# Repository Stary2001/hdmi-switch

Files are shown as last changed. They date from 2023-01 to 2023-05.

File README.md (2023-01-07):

## USB controlled HDMI Switch

I couldn't find one of these easily, so I decided to make one myself.

This uses a PI3HDX621 `3.4Gbps HDMI1.4b Active 2:1 Switch with ARC and Fast Switching` paired with a SAMD21 microcontroller (because I had some in stock).

The firmware is implemented with my library [libsam](https://github.com/Stary2001/libsam).

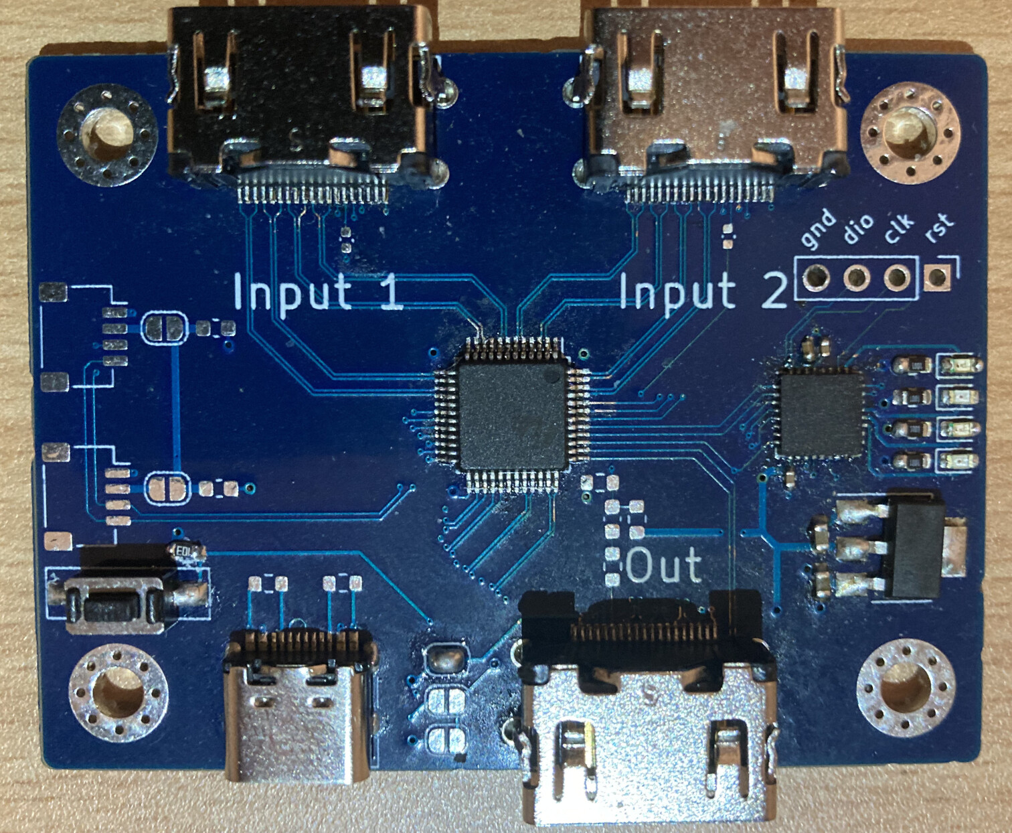
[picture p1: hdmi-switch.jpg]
Picture of the board - with two HDMI ports labelled Input 1 and 2, and a third labelled Out.


Untested things - the switch IC supports ARC, but I didn't test that yet because I don't have anything handy that supports it.

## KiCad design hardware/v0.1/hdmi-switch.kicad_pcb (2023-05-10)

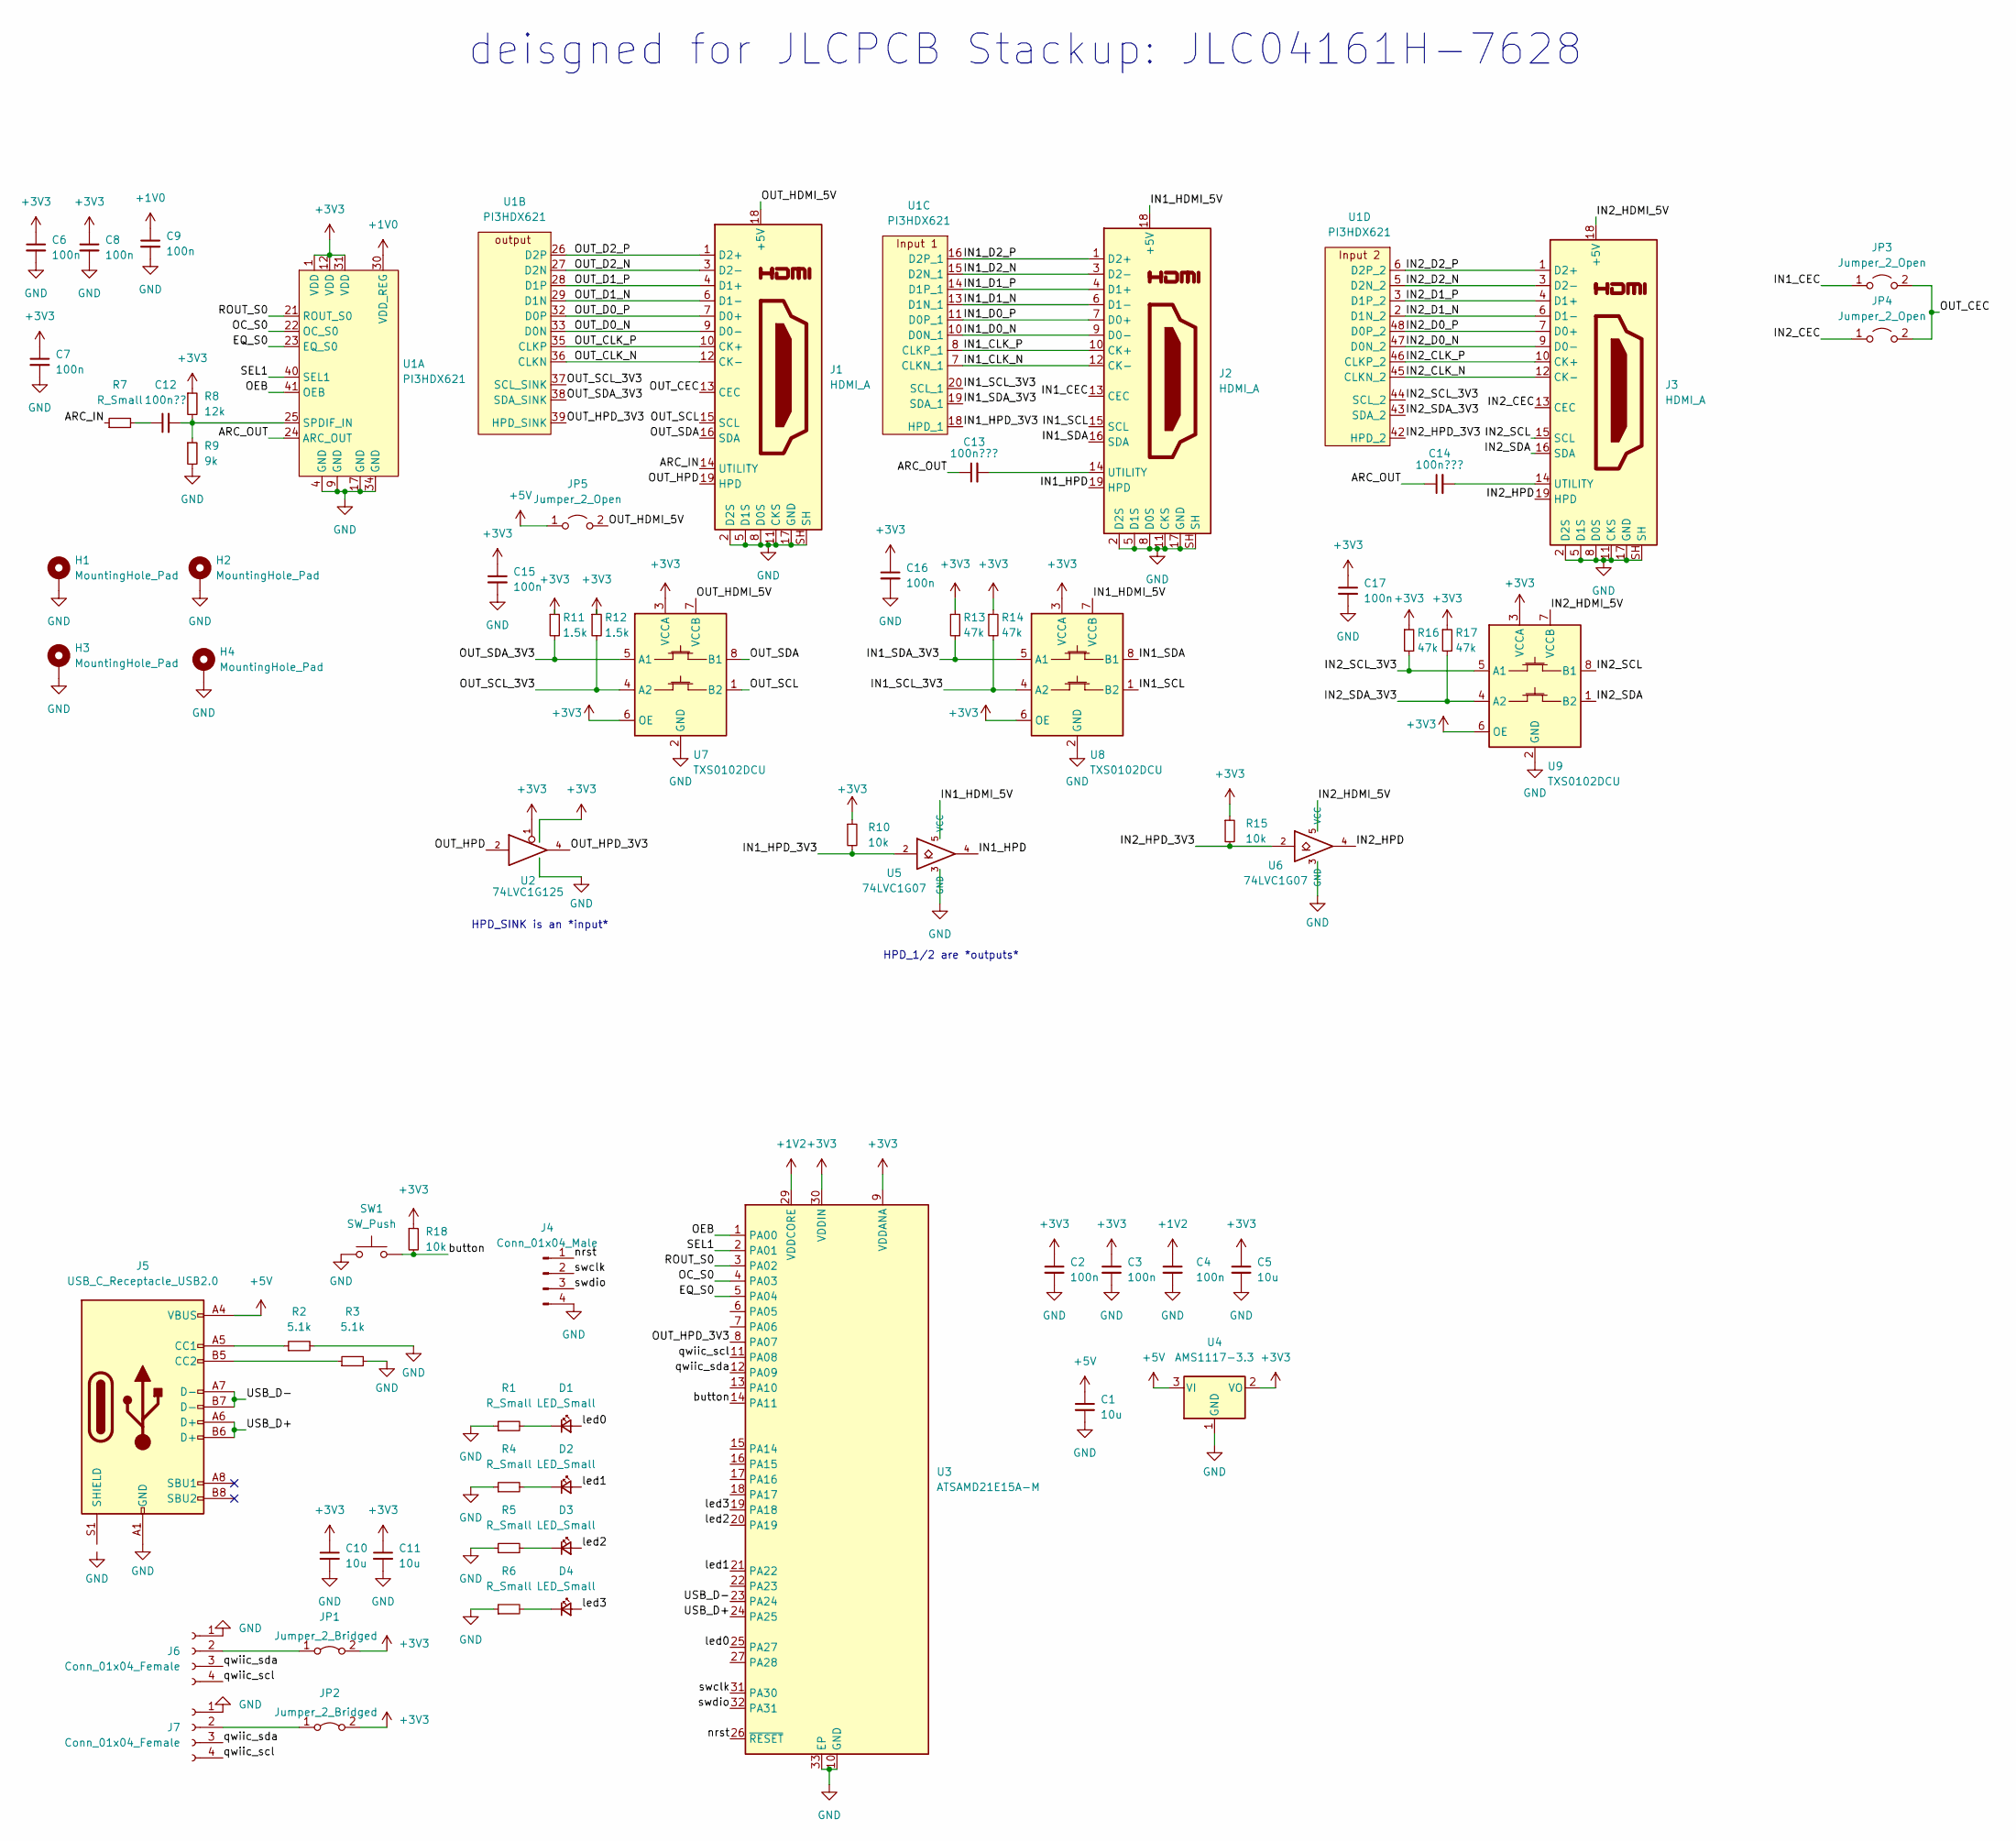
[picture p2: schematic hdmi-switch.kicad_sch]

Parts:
C1, C5, C10, C11: 10u; C_0603_1608Metric
C2, C3, C4, C6, C7, C8, C15, C16, C17: 100n; C_0402_1005Metric
C9: 100n; C_0603_1608Metric
C12: 100n??; C_0603_1608Metric
C13, C14: 100n???; C_0402_1005Metric
D1, D2, D3, D4: LED_Small; LED_0603_1608Metric
H1, H2, H3, H4: MountingHole_Pad; MountingHole_3.2mm_M3_Pad_Via
J1, J2, J3: HDMI_A; HDMI-SS-53000
J4: Conn_01x04_Male; PinHeader_1x04_P2.54mm_Vertical
J5: USB_C_Receptacle_USB2.0; USB_C_Receptacle_HRO_TYPE-C-31-M-12
J6, J7: Conn_01x04_Female; JST_SH_SM04B-SRSS-TB_1x04-1MP_P1.00mm_Horizontal
JP1, JP2: Jumper_2_Bridged; SolderJumper-2_P1.3mm_Open_RoundedPad1.0x1.5mm
JP3, JP4, JP5: Jumper_2_Open; SolderJumper-2_P1.3mm_Open_RoundedPad1.0x1.5mm
R1, R4, R5, R6, R7: R_Small; R_0603_1608Metric
R2, R3: 5.1k; R_0603_1608Metric
R8: 12k; R_0603_1608Metric
R9: 9k; R_0603_1608Metric
R10, R15, R18: 10k; R_0603_1608Metric
R11, R12: 1.5k; R_0603_1608Metric
R13, R14, R16, R17: 47k; R_0603_1608Metric
SW1: SW_Push; PTS636
U1: PI3HDX621; LQFP-48_7x7mm_P0.5mm
U2: 74LVC1G125; SOT-23-5
U3: ATSAMD21E15A-M; QFN-32-1EP_5x5mm_P0.5mm_EP3.6x3.6mm
U4: AMS1117-3.3; SOT-223-3_TabPin2
U5, U6: 74LVC1G07; SOT-23-5
U7, U8, U9: TXS0102DCU; VSSOP-8_2.3x2mm_P0.5mm

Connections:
+1V0: C9.1, U1.30 (VDD_REG)
+1V2: C4.1, U3.29 (VDDCORE)
+3V3: C2.1, C3.1, C5.1, C6.1, C7.1, C8.1, C10.1, C11.1, C15.1, C16.1, C17.1, JP1.2 (B), JP2.2 (B), R8.1, R10.1, R11.1, R12.1, R13.1, R14.1, R15.1, R16.1, R17.1, R18.1, U1.1 (VDD), U1.12 (VDD), U1.31 (VDD), U2.1, U2.5 (VCC), U3.9 (VDDANA), U3.30 (VDDIN), U4.2 (VO), U7.3 (VCCA), U7.6 (OE), U8.3 (VCCA), U8.6 (OE), U9.3 (VCCA), U9.6 (OE)
+5V: C1.1, J5.A4 (VBUS), J5.A9 (VBUS), J5.B4 (VBUS), J5.B9 (VBUS), JP5.1 (A), U4.3 (VI)
/ARC_IN: J1.14 (UTILITY), R7.1
/ARC_OUT: C13.1, C14.1, U1.24 (ARC_OUT)
/EQ_S0: U1.23 (EQ_S0), U3.5 (PA04)
/IN1_CEC: J2.13 (CEC), JP3.1 (A)
/IN1_CLK_N: J2.12 (CK-), U1.7 (CLKN_1)
/IN1_CLK_P: J2.10 (CK+), U1.8 (CLKP_1)
/IN1_D0_N: J2.9 (D0-), U1.10 (D0N_1)
/IN1_D0_P: J2.7 (D0+), U1.11 (D0P_1)
/IN1_D1_N: J2.6 (D1-), U1.13 (D1N_1)
/IN1_D1_P: J2.4 (D1+), U1.14 (D1P_1)
/IN1_D2_N: J2.3 (D2-), U1.15 (D2N_1)
/IN1_D2_P: J2.1 (D2+), U1.16 (D2P_1)
/IN1_HDMI_5V: J2.18 (+5V), U5.5 (VCC), U8.7 (VCCB)
/IN1_HPD: J2.19 (HPD), U5.4
/IN1_HPD_3V3: R10.2, U1.18 (HPD_1), U5.2
/IN1_SCL: J2.15 (SCL), U8.1 (B2)
/IN1_SCL_3V3: R14.2, U1.20 (SCL_1), U8.4 (A2)
/IN1_SDA: J2.16 (SDA), U8.8 (B1)
/IN1_SDA_3V3: R13.2, U1.19 (SDA_1), U8.5 (A1)
/IN2_CEC: J3.13 (CEC), JP4.1 (A)
/IN2_CLK_N: J3.12 (CK-), U1.45 (CLKN_2)
/IN2_CLK_P: J3.10 (CK+), U1.46 (CLKP_2)
/IN2_D0_N: J3.9 (D0-), U1.47 (D0N_2)
/IN2_D0_P: J3.7 (D0+), U1.48 (D0P_2)
/IN2_D1_N: J3.6 (D1-), U1.2 (D1N_2)
/IN2_D1_P: J3.4 (D1+), U1.3 (D1P_2)
/IN2_D2_N: J3.3 (D2-), U1.5 (D2N_2)
/IN2_D2_P: J3.1 (D2+), U1.6 (D2P_2)
/IN2_HDMI_5V: J3.18 (+5V), U6.5 (VCC), U9.7 (VCCB)
/IN2_HPD: J3.19 (HPD), U6.4
/IN2_HPD_3V3: R15.2, U1.42 (HPD_2), U6.2
/IN2_SCL: J3.15 (SCL), U9.8 (B1)
/IN2_SCL_3V3: R16.2, U1.44 (SCL_2), U9.5 (A1)
/IN2_SDA: J3.16 (SDA), U9.1 (B2)
/IN2_SDA_3V3: R17.2, U1.43 (SDA_2), U9.4 (A2)
/OC_S0: U1.22 (OC_S0), U3.4 (PA03)
/OEB: U1.41 (OEB), U3.1 (PA00)
/OUT_CEC: J1.13 (CEC), JP3.2 (B), JP4.2 (B)
/OUT_CLK_N: J1.12 (CK-), U1.36 (CLKN)
/OUT_CLK_P: J1.10 (CK+), U1.35 (CLKP)
/OUT_D0_N: J1.9 (D0-), U1.33 (D0N)
/OUT_D0_P: J1.7 (D0+), U1.32 (D0P)
/OUT_D1_N: J1.6 (D1-), U1.29 (D1N)
/OUT_D1_P: J1.4 (D1+), U1.28 (D1P)
/OUT_D2_N: J1.3 (D2-), U1.27 (D2N)
/OUT_D2_P: J1.1 (D2+), U1.26 (D2P)
/OUT_HDMI_5V: J1.18 (+5V), JP5.2 (B), U7.7 (VCCB)
/OUT_HPD: J1.19 (HPD), U2.2
/OUT_HPD_3V3: U1.39 (HPD_SINK), U2.4, U3.8 (PA07)
/OUT_SCL: J1.15 (SCL), U7.1 (B2)
/OUT_SCL_3V3: R12.2, U1.37 (SCL_SINK), U7.4 (A2)
/OUT_SDA: J1.16 (SDA), U7.8 (B1)
/OUT_SDA_3V3: R11.2, U1.38 (SDA_SINK), U7.5 (A1)
/ROUT_S0: U1.21 (ROUT_S0), U3.3 (PA02)
/SEL1: U1.40 (SEL1), U3.2 (PA01)
/USB_D+: J5.A6 (D+), J5.B6 (D+), U3.24 (PA25)
/USB_D-: J5.A7 (D-), J5.B7 (D-), U3.23 (PA24)
/button: R18.2, SW1.2, U3.14 (PA11)
/led0: D1.2 (A), U3.25 (PA27)
/led1: D2.2 (A), U3.21 (PA22)
/led2: D3.2 (A), U3.20 (PA19)
/led3: D4.2 (A), U3.19 (PA18)
/nrst: J4.1, U3.26 (~RESET)
/qwiic_scl: J6.4, J7.4, U3.11 (PA08)
/qwiic_sda: J6.3, J7.3, U3.12 (PA09)
/swclk: J4.2, U3.31 (PA30)
/swdio: J4.3, U3.32 (PA31)
GND: C1.2, C2.2, C3.2, C4.2, C5.2, C6.2, C7.2, C8.2, C9.2, C10.2, C11.2, C15.2, C16.2, C17.2, H1.1, H2.1, H3.1, H4.1, J1.2 (D2S), J1.5 (D1S), J1.8 (D0S), J1.11 (CKS), J1.17 (GND), J1.SH, J2.2 (D2S), J2.5 (D1S), J2.8 (D0S), J2.11 (CKS), J2.17 (GND), J2.SH, J3.2 (D2S), J3.5 (D1S), J3.8 (D0S), J3.11 (CKS), J3.17 (GND), J3.SH, J4.4, J5.A1 (GND), J5.A12 (GND), J5.B1 (GND), J5.B12 (GND), J6.1, J7.1, R1.1, R2.2, R3.2, R4.1, R5.1, R6.1, R9.2, SW1.1, U1.4 (GND), U1.9 (GND), U1.17 (GND), U1.34 (GND), U2.3 (GND), U3.10 (GND), U3.28 (GND), U3.33 (EP), U4.1 (GND), U5.3 (GND), U6.3 (GND), U7.2 (GND), U8.2 (GND), U9.2 (GND)
unnamed: C12.1, R7.2
unnamed: C12.2, R8.2, R9.1, U1.25 (SPDIF_IN)
unnamed: C13.2, J2.14 (UTILITY)
unnamed: C14.2, J3.14 (UTILITY)
unnamed: D1.1 (K), R1.2
unnamed: D2.1 (K), R4.2
unnamed: D3.1 (K), R5.2
unnamed: D4.1 (K), R6.2
unnamed: J5.A5 (CC1), R2.1
unnamed: J5.B5 (CC2), R3.1
unnamed: J6.2, JP1.1 (A)
unnamed: J7.2, JP2.1 (A)

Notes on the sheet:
deisgned for JLCPCB Stackup: JLC04161H-7628
HPD_SINK is an *input*
HPD_1/2 are *outputs*

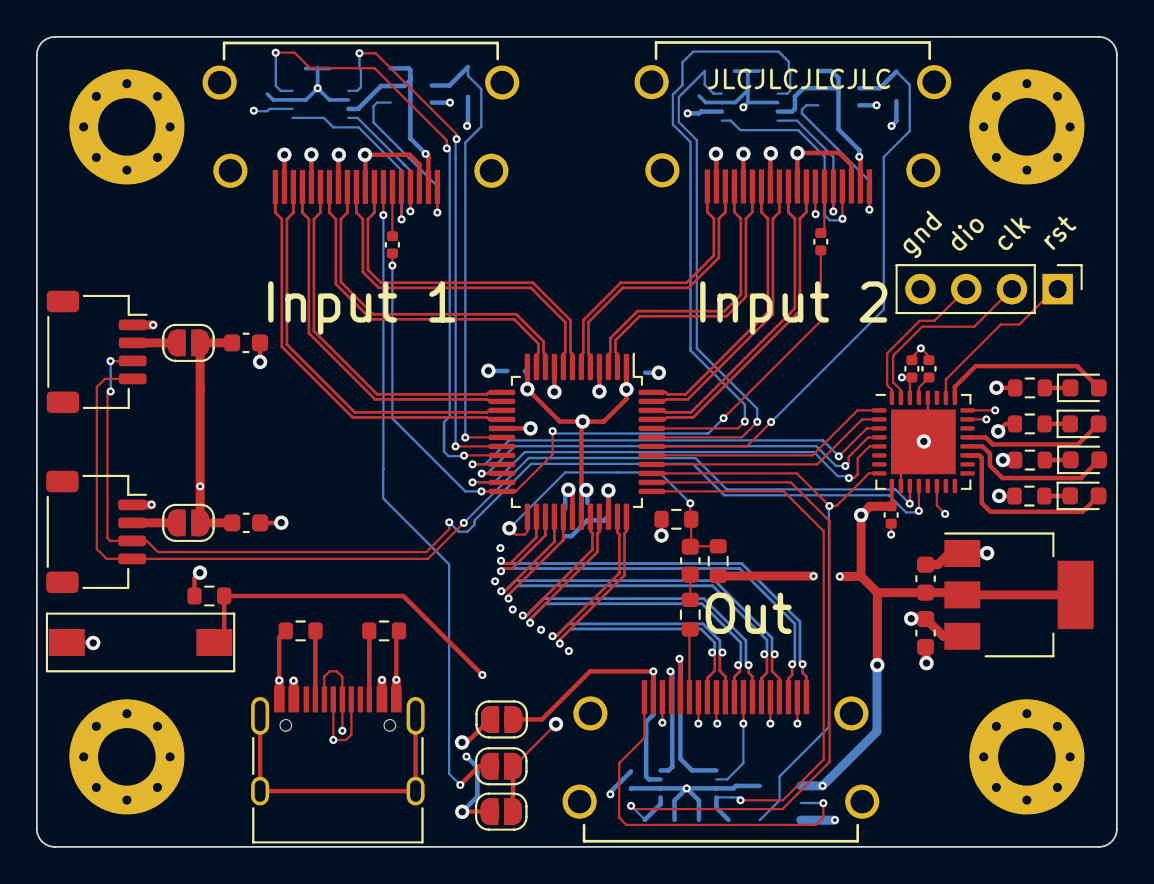
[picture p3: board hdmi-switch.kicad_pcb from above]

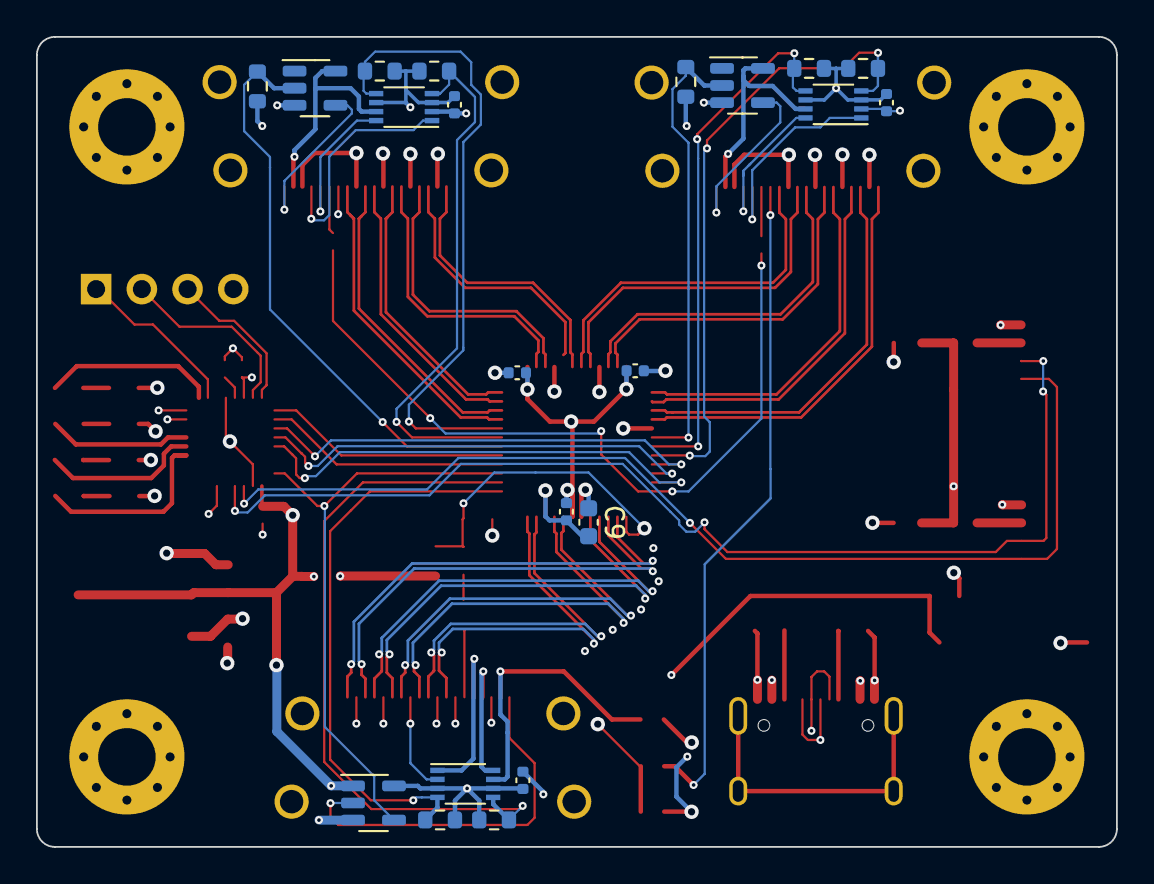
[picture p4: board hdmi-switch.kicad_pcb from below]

Board: 4 copper layers, 60.0 x 45.0 mm, 65 parts (21 on the bottom side), 84 nets.

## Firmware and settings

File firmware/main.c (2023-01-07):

#include <stdio.h>
#include "sam/gpio.h"
#include "sam/bod.h"
#include "sam/clock.h"
#include "sam/sercom_usart.h"
#include "sam/pinmux.h"
#include "sam/serial_number.h"

#include "tusb.h"

void USB_Handler() {
	tud_int_handler(0);
}

volatile uint32_t system_ticks = 0;
void SysTick_Handler (void)
{
	system_ticks++;
}

// GPIO pin definitions
const int OE_B = 0;
const int SEL1 = 1;
const int ROUT_S0 = 2;
const int OC_S0 = 3;
const int EQ_S0 = 4;

const int HPD_IN = 7;

const int LED0 = 27;
const int LED1 = 22;
const int LED2 = 19;
const int LED3 = 18;

const int BUTTON = 11;

bool current_output = true;
static void switch_to_output(bool out) {
	current_output = out;
	if(current_output) {
		port_set_value(1, true);
		port_set_value(LED0, true);
		port_set_value(LED3, false);
	} else {
		port_set_value(1, false);
		port_set_value(LED0, false);
		port_set_value(LED3, true);
	}
}

static void cdc_task(void) {
	if (tud_cdc_n_available(0)) {
		uint8_t buf[64];
		uint32_t count = tud_cdc_n_read(0, buf, sizeof(buf));

		for(uint32_t i = 0; i < count; i++) {
			if(buf[i] == '1') {
				switch_to_output(true); // switch to 1
			} else if(buf[i] == '2') {
				switch_to_output(false); // switch to 2
			}
		}
	}
}

static void button_task(void) {
	static int last_tick = 0;
	static bool waiting_for_low = false;

	bool button_value = !port_get_value(BUTTON);
	if(button_value && !waiting_for_low) {
		if(system_ticks - last_tick > 100) {
			last_tick = system_ticks;
			waiting_for_low = true;
			switch_to_output(!current_output);
		}
	} else if(!button_value) {
		waiting_for_low = false;
	}
}

extern char const* string_desc_arr [];

int main() {
	clock_switch_to_8mhz();
	bod_init();
	bod_set_3v3();

	clock_switch_to_48mhz_from_usb();
	clock_setup_gclk2_8mhz();
	clock_setup_usb();

	clock_setup_systick_1ms();

	port_set_direction(OE_B, true);
	port_set_direction(SEL1, true);
	port_set_direction(ROUT_S0, true);
	port_set_direction(OC_S0, true);
	port_set_direction(EQ_S0, true);

	port_set_direction(HPD_IN, false);

	port_set_direction(LED0, true);
	port_set_direction(LED1, true);
	port_set_direction(LED2, true);
	port_set_direction(LED3, true);

	port_set_value(LED0, true);
	port_set_value(LED1, false);
	port_set_value(LED2, false);
	port_set_value(LED3, false);

	port_set_direction(BUTTON, false);

	port_set_value(OE_B, false); // oeb low = enable
	port_set_value(SEL1, true); // sel1 high = port 1 select
	port_set_value(ROUT_S0, true); // rout_s0 high = 50ohm termination
	port_set_value(OC_S0, false); // low = 0db pre-emphasis
	port_set_value(EQ_S0, false); // low = 9db eq

	pinmux_setup_usb();

	string_desc_arr[3] = (const char *) serial_get_hash_hex();

	tusb_init();
	tud_init(0);

	while(true) {
		tud_task();
		cdc_task();
		button_task();
	}

	return 0;
}

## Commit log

2023-01-07 update firmware - enable systick so button actually works
2023-05-10 add gitignore, move hardware to 0.1
    [hdmi-switch.kicad_pcb, hdmi-switch.kicad_sch]
